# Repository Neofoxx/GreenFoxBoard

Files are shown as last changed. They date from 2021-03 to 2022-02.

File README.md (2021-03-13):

# GreenFoxBoard
This is a small PIC32MM GPM development board.

#### Schematic
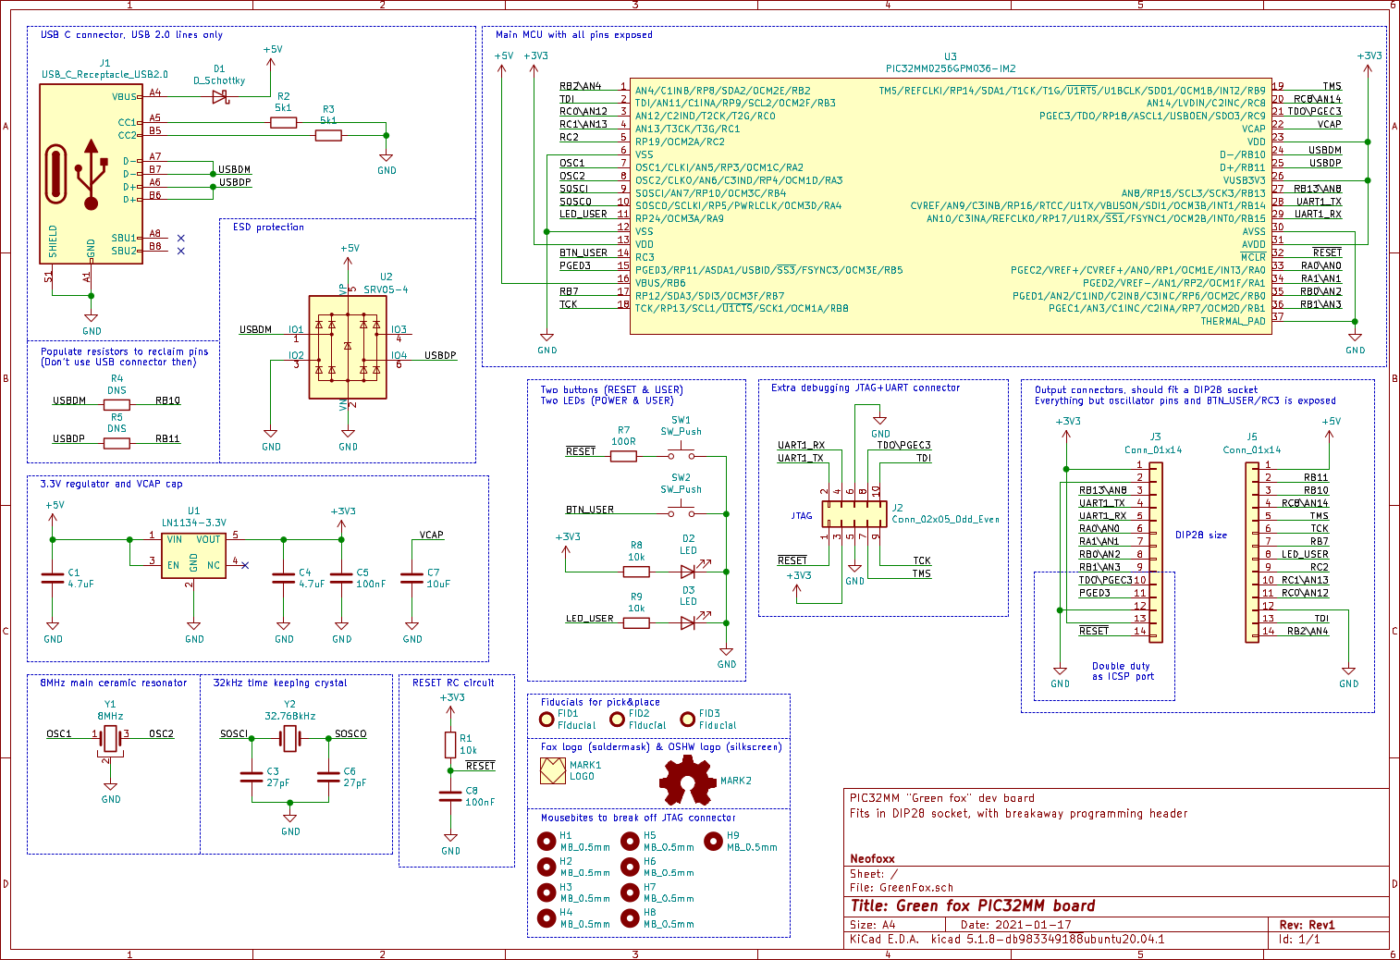
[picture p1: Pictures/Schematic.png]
Schematic


#### Render
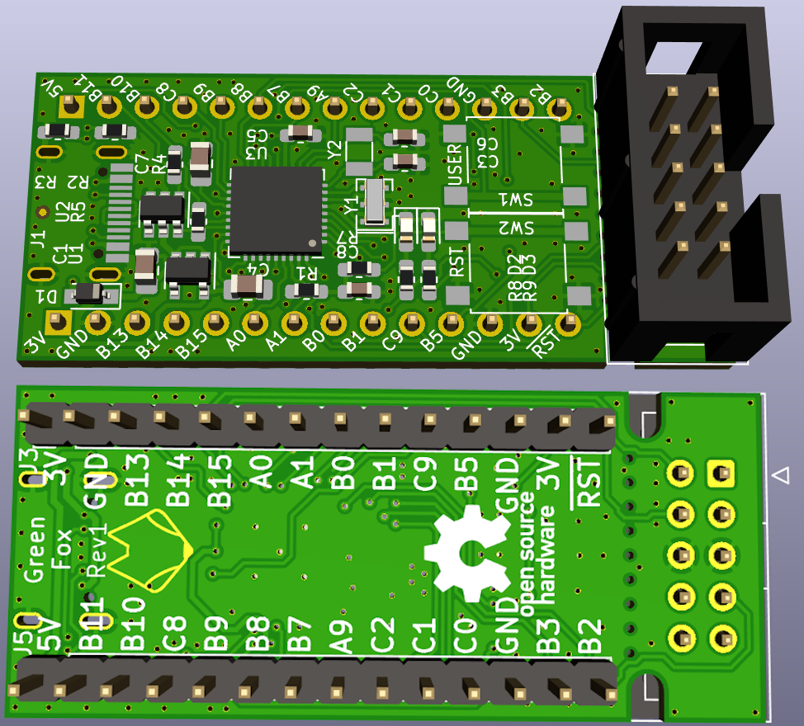
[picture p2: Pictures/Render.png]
Render


#### PCB
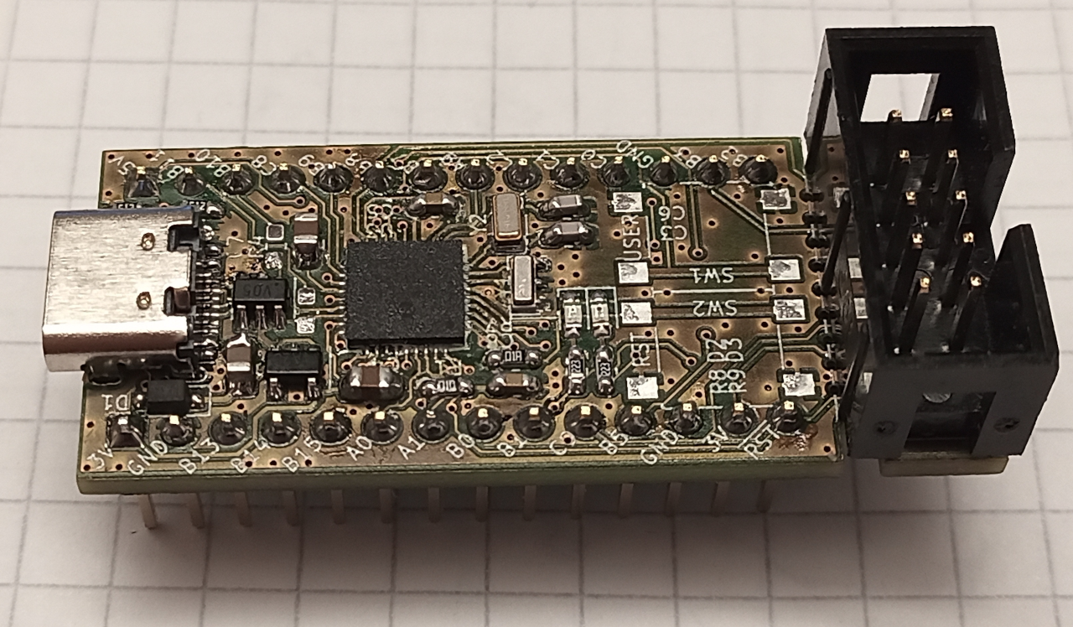
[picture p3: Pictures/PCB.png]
PCB


## Description
This is a small PIC32MM dev board, for the GPM series of parts (aka /w USB support).

The idea is to have a board, that can be quickly used with the [open-source toolchain for PIC32s](https://gitlab.com/spicastack/pic32-parts-free).

The feature list is as follows:
- PIC32MM0256GPM036-I/M2, 2.0V to 3.6V, 25MHz max., 256kB flash, 32kB RAM
- USB-C connector
- ESD protection on USB pins
- Two LEDs, one Power, one User
- Two buttons, one Reset, one User
- Components only on one side
- Fits into 28-pin DIP socket (wide)
- Breakaway section on the PCB, with a JTAG+UART connector for easy programming
- Pin markings on both top and bottom

The JTAG+UART connector is there for ease of access. You can also score the vias with a knife, and break that part off. The JTAG+UART pins are also available on other pins, not just on the breakaway.

ICSP pins are routed to the bottom left of the board, in a standard ICD/PICkit pinout, for easy connecting.

Two crystals are present - an 8MHz one and a 32.768kHz one. Pins used for these crystals are not routed to the header pins.

USB works without any crystals - USB clock tuning on-the-go built into the peripheral is confirmed working. Tested with a modified version of [m-stack](https://github.com/signal11/m-stack).

## Notes

Be careful when ordering the chips, as theee are two 36-pin namings, but one actually has 40-pins. You needs the PIC32MM0256GPM036-I/**M2** version, **not MV**

Make sure to use the latest fersion of [Progyon](https://gitlab.com/spicastack/progyon) for programming, as it includes a fix that previously disabled JTAG pins for use during runtime.

## Files
* The Gerber files are in the HW/GreenFox/Gerbers directory
* The BOM is in the HW/GreenFox/ibom directory
* The schematic is here in the root directory

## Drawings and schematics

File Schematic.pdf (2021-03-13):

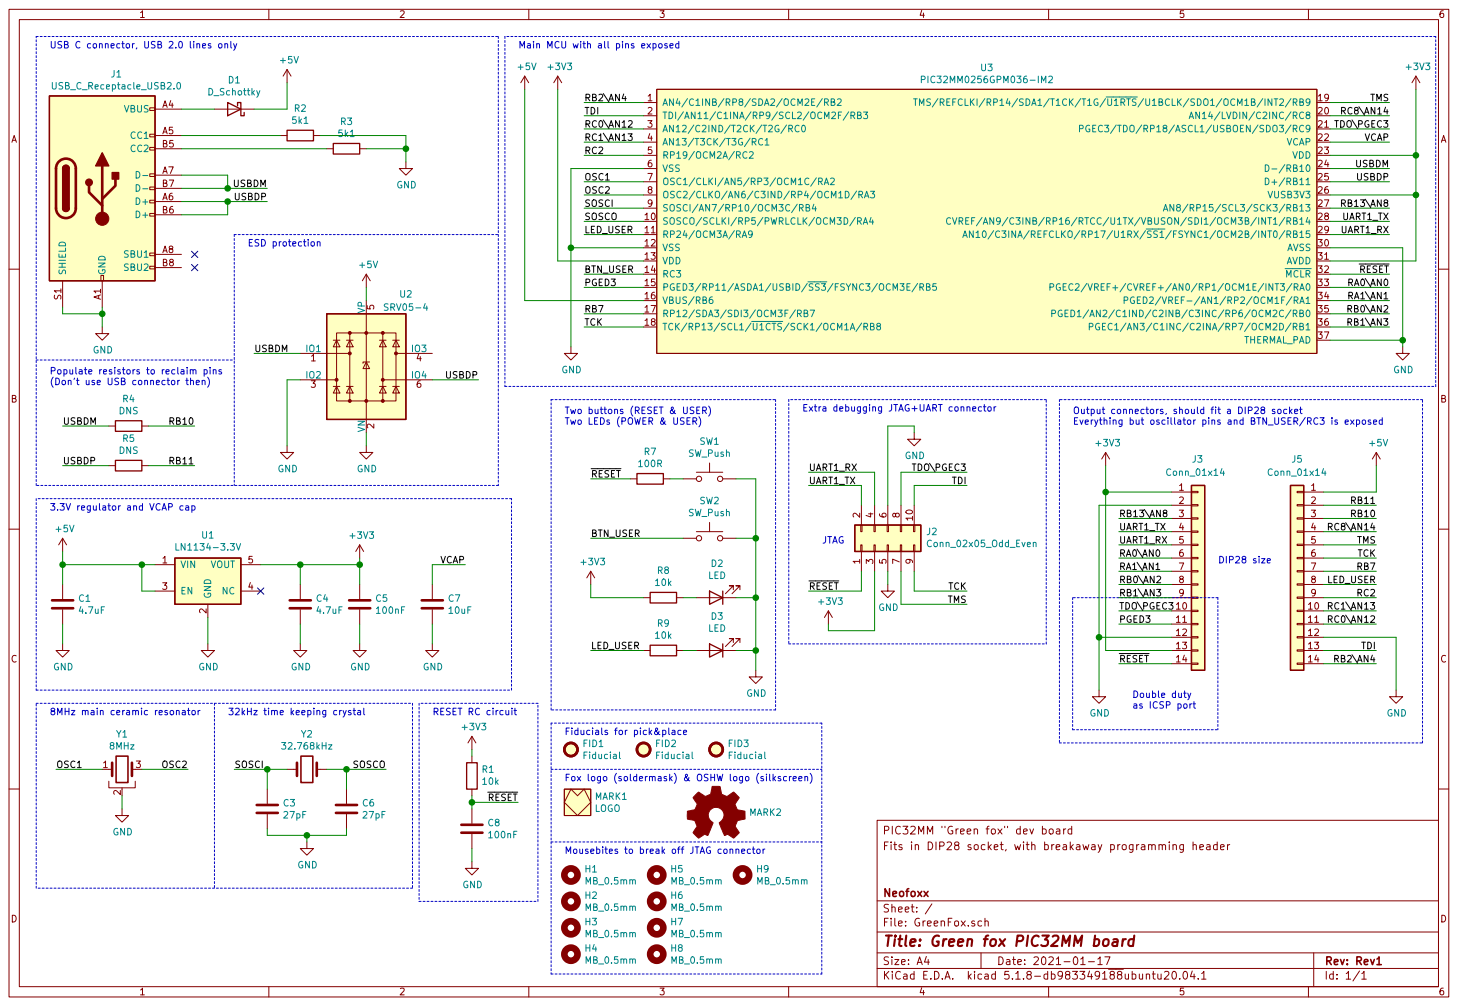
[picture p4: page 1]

USB C connector, USB 2.0 lines only

(Don't use USB connector then)

RB11 Two buttons (RESET & USER)
Two LEDs (POWER & USER)

Output connectors, should fit a DIP28 socket
Everything but oscillator pins and BTN_USER/RC3 is exposed

3.3V regulator and VCAP cap

Fiducials for pick&place

Fox logo (soldermask) & OSHW logo (silkscreen)

File: GreenFox.sch Sheet: / Neofoxx Fits in DIP28 socket, with breakaway programming header PIC32MM "Green fox" dev board C6

Id: 1/1 Title: Green fox PIC32MM board

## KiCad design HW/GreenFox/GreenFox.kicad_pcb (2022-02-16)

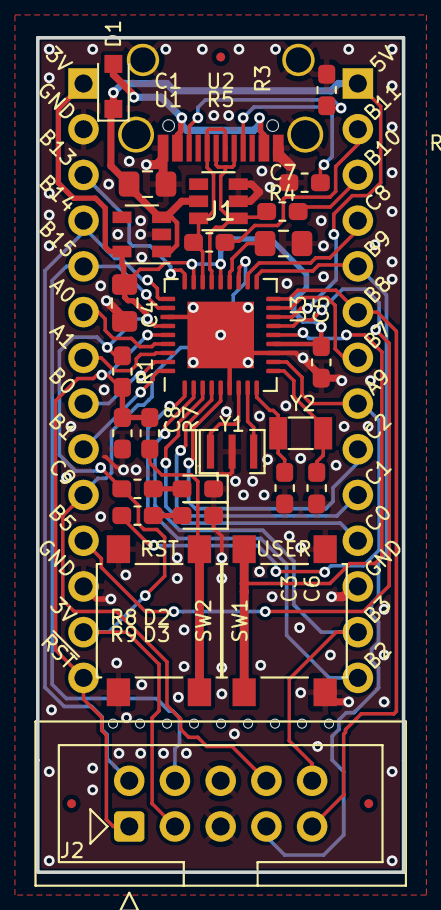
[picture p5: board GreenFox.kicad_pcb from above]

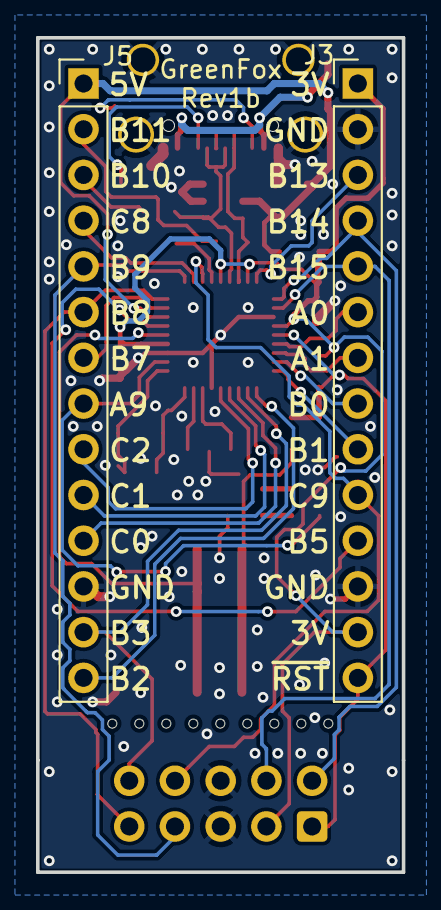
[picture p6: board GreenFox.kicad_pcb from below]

Board: 2 copper layers, 20.3 x 46.4 mm, 42 parts (3 on the bottom side), 39 nets.

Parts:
C1, C4: 4.7uF; C_0805_2012Metric_Pad1.15x1.40mm_HandSolder
C3, C6: 27pF; C_0603_1608Metric_Pad1.05x0.95mm_HandSolder
C5, C8: 100nF; C_0603_1608Metric_Pad1.05x0.95mm_HandSolder
C7: 10uF; C_0805_2012Metric_Pad1.15x1.40mm_HandSolder
D1: D_Schottky; D_SOD-323_HandSoldering
D2, D3: LED; LED_0603_1608Metric_Pad1.05x0.95mm_HandSolder
FID1, FID2, FID3: Fiducial; Fiducial_0.5mm_Mask1mm
H1, H2, H3, H4, H5, H6, H7, H8, H9: MB_0.5mm; MouseBiteHole_0.5mm
J1: USB_C_Receptacle_USB2.0; Jing_USB_C_2_0_16pin_receptable_noSlots
J2: Conn_02x05_Odd_Even; IDC-Header_2x05_P2.54mm_Vertical
J3, J5: Conn_01x14; PinHeader_1x14_P2.54mm_Vertical
MARK1: LOGO; FOX_LOGO_MASK
R1, R8, R9: 10k; R_0603_1608Metric_Pad1.05x0.95mm_HandSolder
R2, R3: 5k1; R_0603_1608Metric_Pad1.05x0.95mm_HandSolder
R4, R5: DNS; R_0603_1608Metric_Pad1.05x0.95mm_HandSolder
R7: 100R; R_0603_1608Metric_Pad1.05x0.95mm_HandSolder
SW1, SW2: SW_Push; SW_SPST_B3S-1000
U1: LN1134-3.3V; SOT-23-5
U2: SRV05-4; SOT-23-6
U3: PIC32MM0256GPM036-IM2; QFN-36-1EP_6x6mm_P0.5mm_EP3.7x3.7mm
Y1: 8MHz; Resonator_SMD_muRata_CSTxExxV-3Pin_3.0x1.1mm
Y2: 32.768kHz; Crystal_SMD_3215-2Pin_3.2x1.5mm

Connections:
+3V3: C4.1, C5.1, J2.3, J3.1, J3.13, R1.2, R8.2, U1.5 (VOUT), U3.13 (VDD), U3.23 (VDD), U3.26 (VUSB3V3), U3.31 (AVDD)
+5V: C1.1, D1.1 (K), J5.1, U1.1 (VIN), U1.3 (EN), U2.5 (VP), U3.16 (VBUS/RB6)
/BTN_USER: SW2.1, U3.14 (RC3)
/LED_USER: J5.8, R9.2, U3.11 (RP24/OCM3A/RA9)
/OSC1: U3.7 (OSC1/CLKI/AN5/RP3/OCM1C/RA2), Y1.1
/OSC2: U3.8 (OSC2/CLKO/AN6/C3IND/RP4/OCM1D/RA3), Y1.3
/PGED3: J3.11, U3.15 (PGED3/RP11/ASDA1/USBID/~SS3/FSYNC3/OCM3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)
/RA0\AN0: J3.6, U3.33 (PGEC2/VREF+/CVREF+/AN0/RP1/OCM1E/INT3/R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)
/RA1\AN1: J3.7, U3.34 (PGED2/VREF-/AN1/RP2/OCM1F/RA1)
/RB0\AN2: J3.8, U3.35 (PGED1/AN2/C1IND/C2INB/C3INC/RP6/OCM2C/R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)
/RB1\AN3: J3.9, U3.36 (PGEC1/AN3/C1INC/C2INA/RP7/OCM2D/RB1)
/RB2\AN4: J5.14, U3.1 (AN4/C1INB/RP8/SDA2/OCM2E/RB2)
/RB7: J5.7, U3.17 (RP12/SDA3/SDI3/OCM3F/RB7)
/RB10: J5.3, R4.1
/RB11: J5.2, R5.1
/RB13\AN8: J3.3, U3.27 (AN8/RP15/SCL3/SCK3/RB13)
/RC0\AN12: J5.11, U3.3 (AN12/C2IND/T2CK/T2G/RC0)
/RC1\AN13: J5.10, U3.4 (AN13/T3CK/T3G/RC1)
/RC2: J5.9, U3.5 (RP19/OCM2A/RC2)
/RC8\AN14: J5.4, U3.20 (AN14/LVDIN/C2INC/RC8)
/SOSCI: C3.1, U3.9 (SOSCI/AN7/RP10/OCM3C/RB4), Y2.1
/SOSCO: C6.1, U3.10 (SOSCO/SCLKI/RP5/PWRLCLK/OCM3D/RA4), Y2.2
/TCK: J2.9, J5.6, U3.18 (TCK/RP13/SCL1/~U1CTS/SCK1/OCM1A/RB8)
/TDI: J2.10, J5.13, U3.2 (TDI/AN11/C1INA/RP9/SCL2/OCM2F/RB3)
/TDO\PGEC3: J2.8, J3.10, U3.21 (PGEC3/TDO/RP18/ASCL1/USBOEN/SDO3/RC9)
/TMS: J2.7, J5.5, U3.19 (TMS/REFCLKI/RP14/SDA1/T1CK/T1G/~U1RTS/U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)
/UART1_RX: J2.4, J3.5, U3.29 (AN10/C3INA/REFCLKO/RP17/U1RX/~SS1/FSYNC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)
/UART1_TX: J2.2, J3.4, U3.28 (CVREF/AN9/C3INB/RP16/RTCC/U1TX/VBUSON/S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)
/USBDM: J1.A7 (D-), J1.B7 (D-), R4.2, U2.1 (IO1), U3.24 (D-/RB10)
/USBDP: J1.A6 (D+), J1.B6 (D+), R5.2, U2.6 (IO4), U3.25 (D+/RB11)
/VCAP: C7.1, U3.22 (VCAP)
/~RESET: C8.1, J2.1, J3.14, R1.1, R7.2, U3.32 (~MCLR)
GND: C1.2, C3.2, C4.2, C5.2, C6.2, C7.2, C8.2, D2.1 (K), D3.1 (K), J1.A1 (GND), J1.S1 (SHIELD), J2.5, J2.6, J3.2, J3.12, J5.12, R2.1, R3.1, SW1.2, SW2.2, U1.2 (GND), U2.2 (VN), U2.3 (IO2), U3.6 (VSS), U3.12 (VSS), U3.30 (AVSS), U3.37 (THERMAL_PAD), Y1.2
unnamed: D1.2 (A), J1.A4 (VBUS)
unnamed: D2.2 (A), R8.1
unnamed: D3.2 (A), R9.1
unnamed: J1.A5 (CC1), R2.2
unnamed: J1.B5 (CC2), R3.2
unnamed: R7.1, SW1.1

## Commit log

2021-01-15 First try
    [GreenFox.kicad_pcb, GreenFox.sch]
2021-01-16 Finished board, added text, fiducials, logos, etc.
    [GreenFox.kicad_pcb, GreenFox.sch]
2021-01-17 Minor tweaks, added gerbers
    [GreenFox-B_Cu.gbl, GreenFox-B_Mask.gbs, GreenFox-B_SilkS.gbo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]
2021-01-17 Add text to buttons and re-export
    [GreenFox-B_Cu.gbl, GreenFox-B_Mask.gbs, GreenFox-B_SilkS.gbo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]
2021-03-13 Added documentation & pics
    [GreenFox.sch]
2022-02-16 Very quick mod for different fab
    [GreenFox-B_Cu.gbl, GreenFox-B_Cu.gbr, GreenFox-B_Mask.gbr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]
